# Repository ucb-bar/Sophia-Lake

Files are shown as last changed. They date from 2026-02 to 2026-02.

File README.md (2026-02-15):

# **SOPHIA LAKE**

SL back

# Introduction

Sophia Lake is a general-purpose bring-up carrier board optimized for portability. It is designed around the Bora Lake SODIMM interface to allow for compatibility with a wide array of custom SoCs.

****

Sophia Lake

Art by: [@seuiwu](https://www.instagram.com/seuiwu?utm_source=ig_web_button_share_sheet&igsh=ZDNlZDc0MzIxNw==)

# Block Diagram
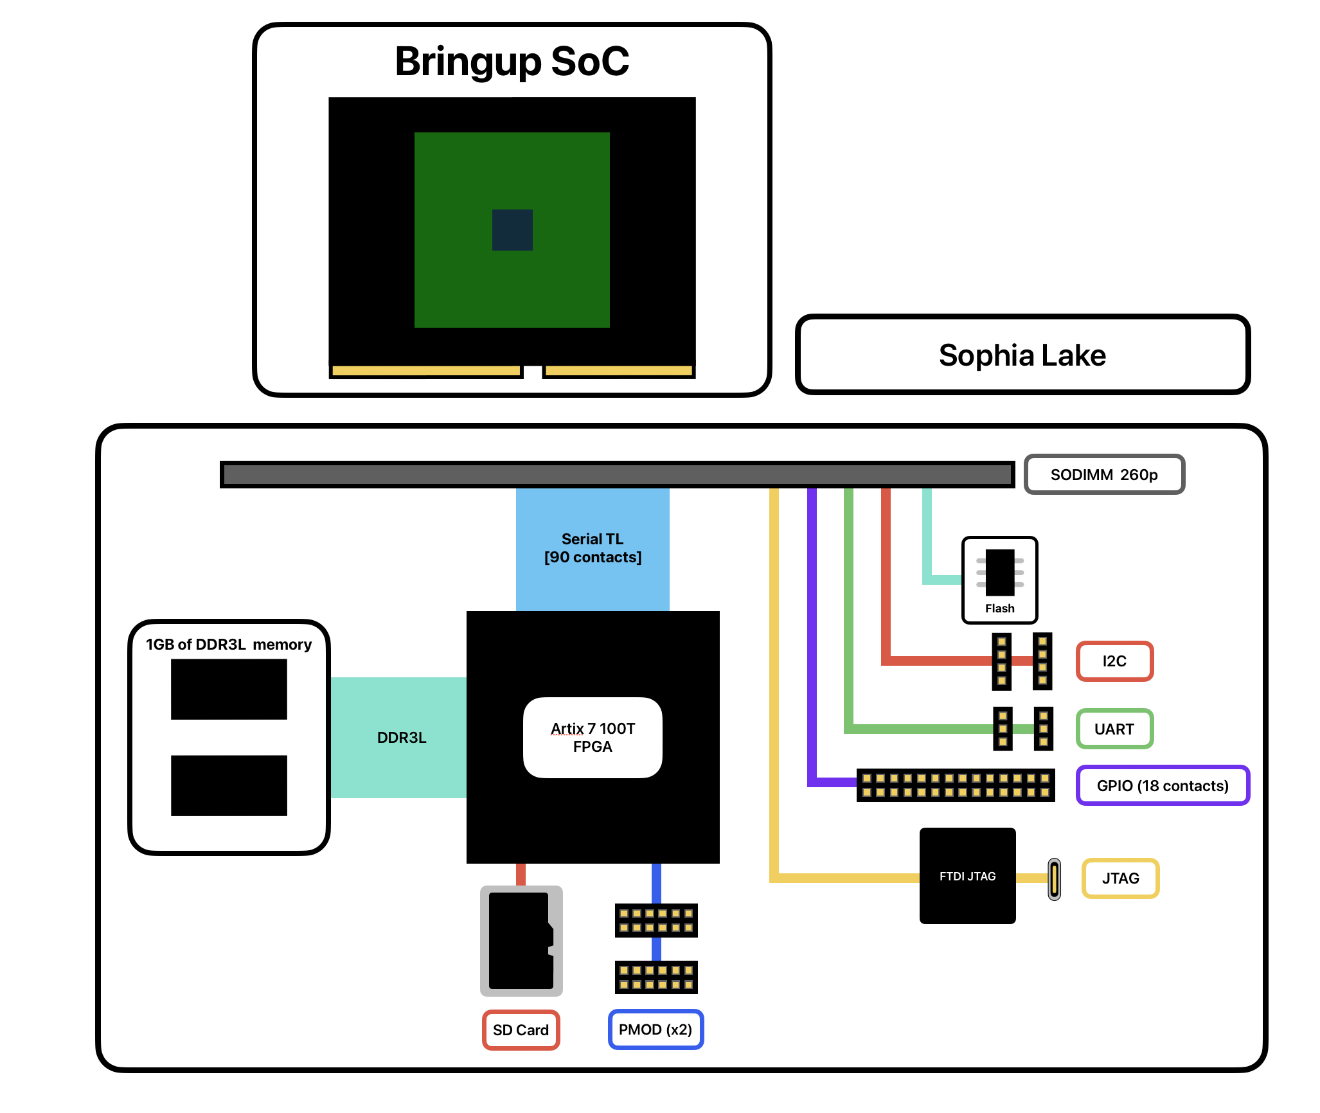
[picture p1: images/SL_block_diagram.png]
Block Diagram


<div style="text-align: center;">

> *"Yufeng's hair style looks like Si-en"*\
>   \- Sophia Shao 

</div>

# Specs
### On-board FPGA
| | Artix A7 100T | Artix A7 200T |
| --- | --- | --- |
| FPGA part | XC7A100T-2FBG484I | XC7A200T-2FBG484I |
| Logic Cells | 101,440 | 215,360 |
| DSP Slices | 240 | 740 | 
| Memory (Kbits) | 4,860 | 13,140 | 

### FPGA Features
- 1GB DDR3L DRAM with 32-bit bus @ 400MHz (800 MT/s)
- 16MB Quad-SPI Flash
- USB-JTAG programming
- MicroSD card slot
- 2x PMOD headers
- 1x Reset button
- 2x Programmable buttons
- 4x LEDs

### SoC Breakout
- 16MB Quad-SPI Flash
- USB-JTAG programming
- Boot select and variable polarity chip reset
- Built-in level shifting to 3.3V
- 4x Programmable buttons
- 4x LEDs
- 2x UART 
- 2x I2C
- 18x GPIO pins

### SoC Power Injection
- Programmable Soc power input
    - VIO input from 1.2V - 3.3V
    - VCORE input from 0.8V - 2.0V
- Optional external power injection
- Shunt resistors for current sensing

# SODIMM Pinout

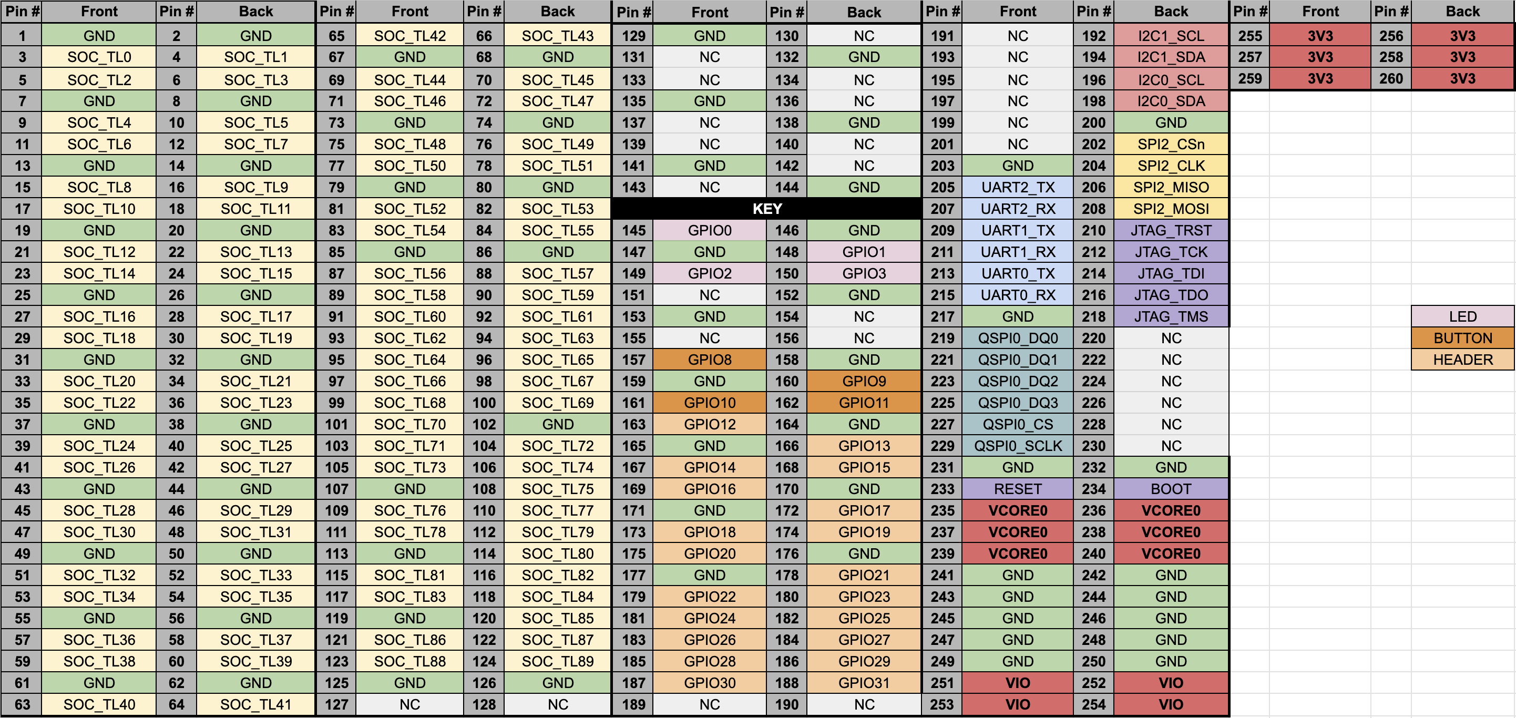
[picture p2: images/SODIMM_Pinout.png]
SODIMM pinout


# Sophia Lake Pinout

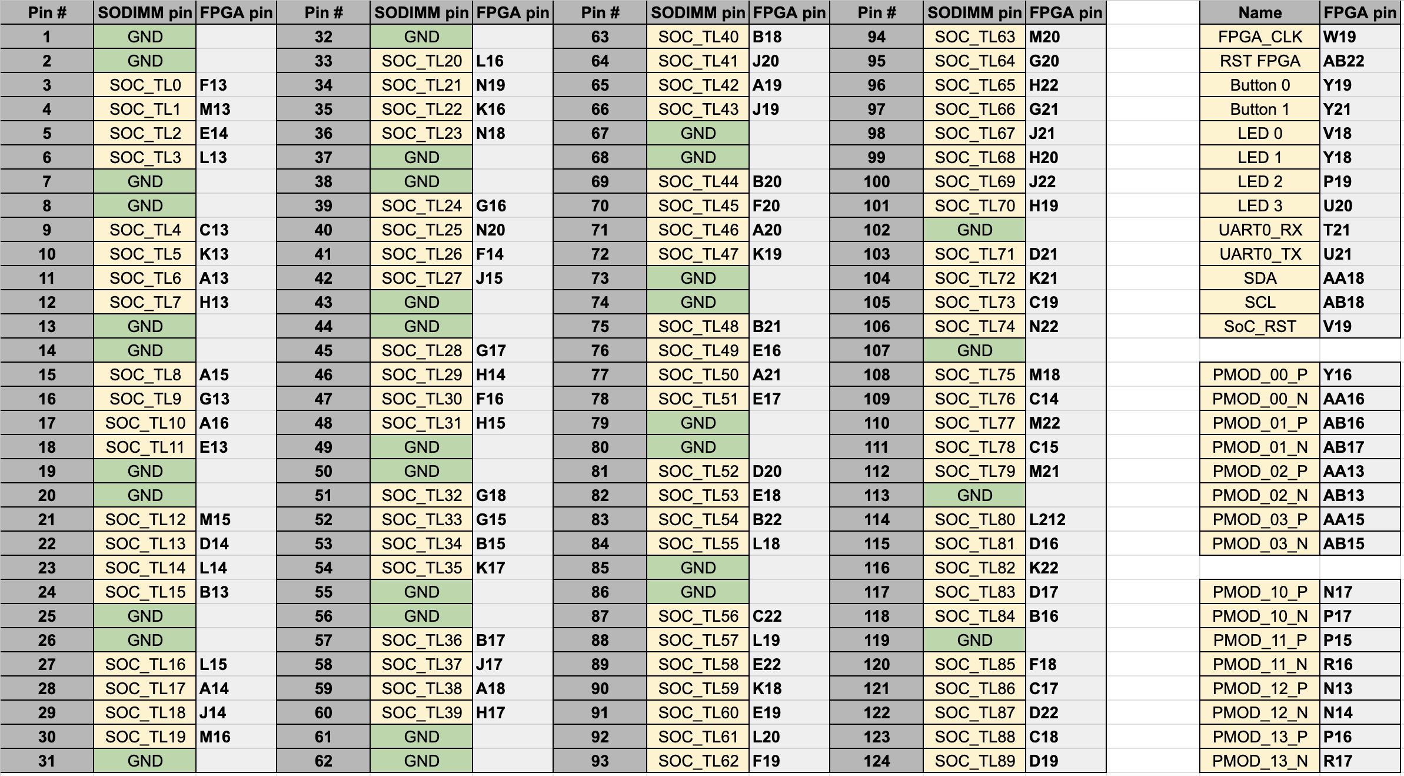
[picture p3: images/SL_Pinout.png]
Sophia Lake pinout


# Board Layout

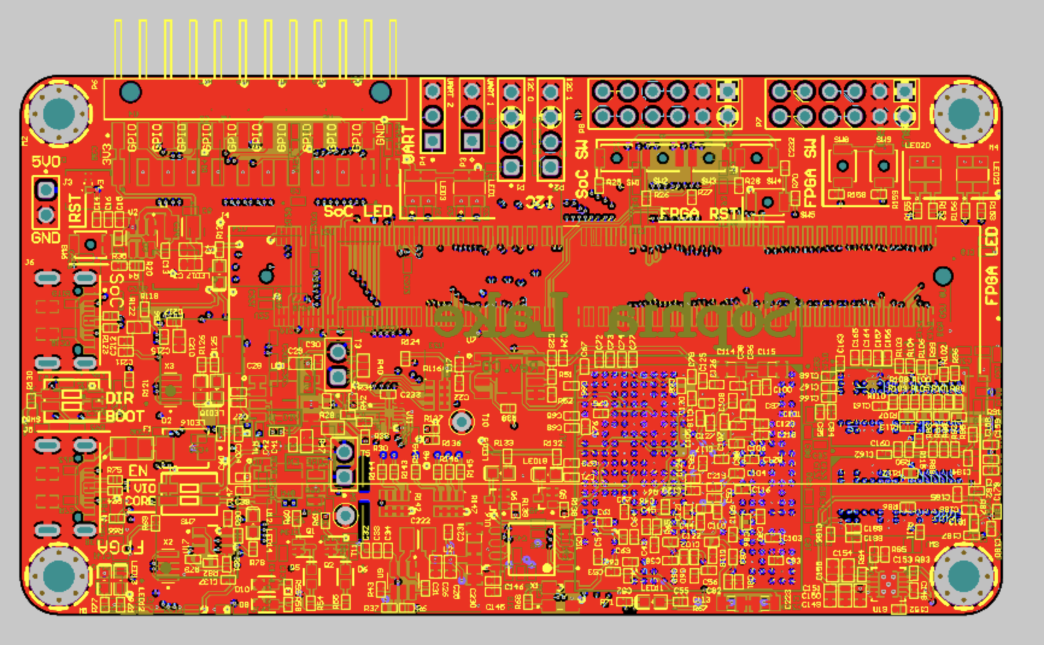
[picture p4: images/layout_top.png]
Layout Top

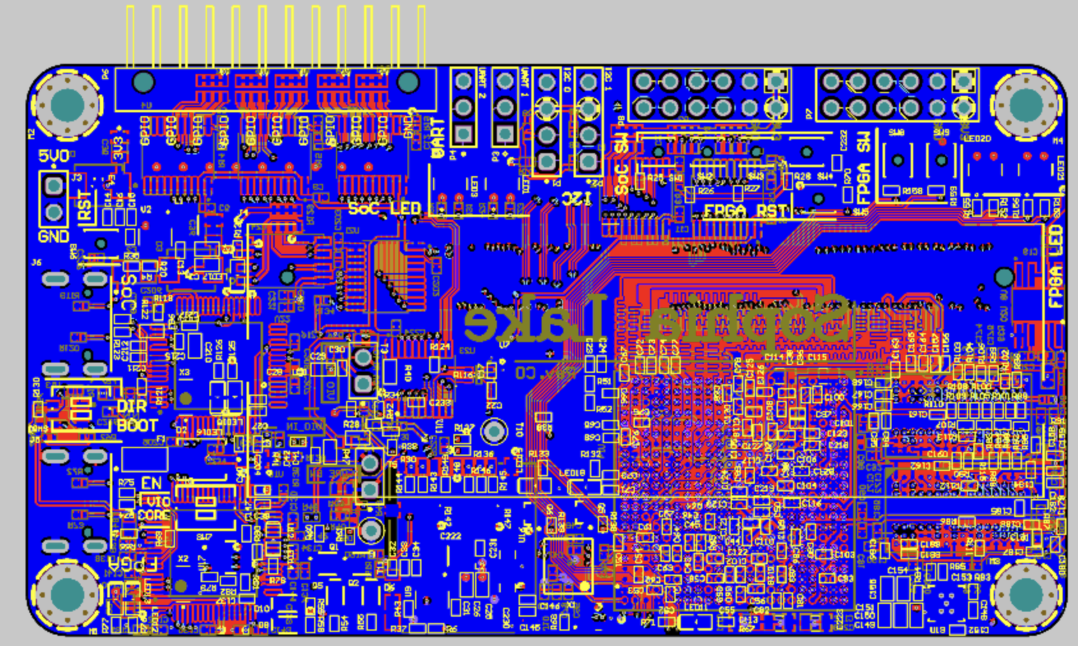
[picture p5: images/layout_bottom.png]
Layout Bottom


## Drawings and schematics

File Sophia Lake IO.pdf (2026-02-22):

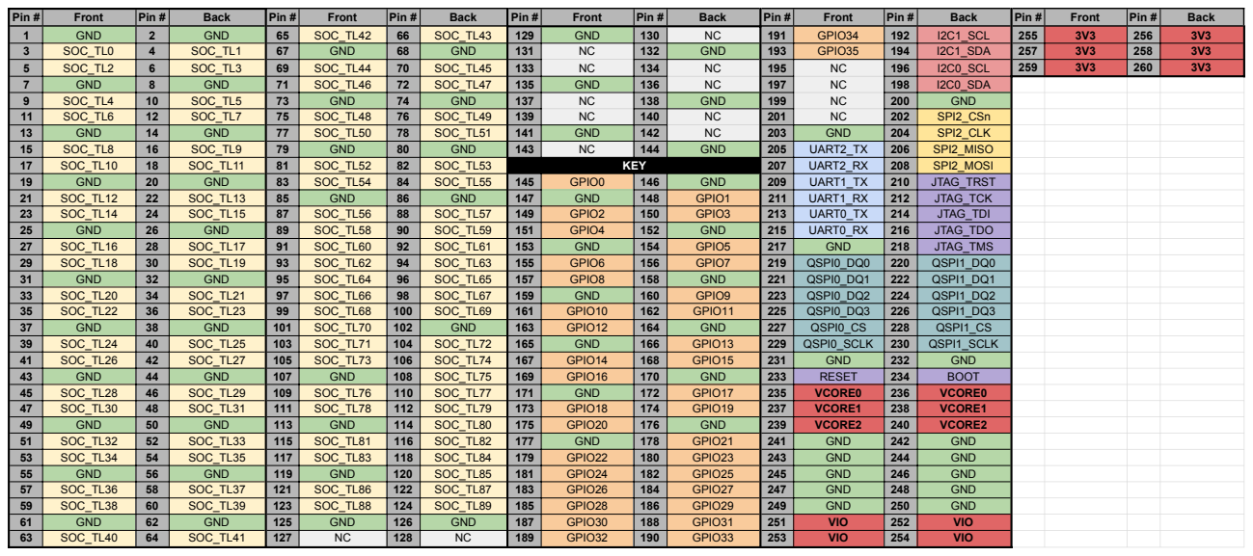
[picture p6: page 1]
Pin #; Front; Back; Back 1; GND; SOC_TL42; SOC_TL43; GPIO34; I2C1_SCL; SOC_TL0; SOC_TL1; GPIO35; I2C1_SDA; SOC_TL2; SOC_TL3; SOC_TL44; SOC_TL45; I2C0_SCL; SOC_TL46; SOC_TL47; I2C0_SDA 9; SOC_TL4; SOC_TL5

11 | SOC_TL6 | 12 | SOC_TL7 | 75 | SOC_TL48 | 76 | SOC_TL49 | 139 | | 140 | NC NC | 201 | | 202 | SPI2_CSn

NC
13 | GND | 14 | GND | 77 | SOC_TL50 | 78 | SOC_TL51 | 141 | GND | 142 | | 203 | GND | 204 | SPI2_CLK
15 | SOC_TL8 | 16 | SOC_TL9 | 79 | GND | 80 | GND | 143 | NC | 144 | GND | 205 | UART2_TX | 206 | SPI2_MISO
17 | SOC_TL10 | 18 | SOC_TL11 | 81 | SOC_TL52 | 82 | SOC_TL53 | KEY | | | | 207 | UART2_RX | 208 | SPI2_MOSI
19 | GND | 20 | GND | 83 | SOC_TL54 | 84 | SOC_TL55 | 145 | GPIO0 GND | 146 | GND | 209 | UART1_TX | 210 | JTAG_TRST
21 | SOC_TL12 | 22 | SOC_TL13 | 85 | GND | 86 | GND | 147 | | 148 | GPIO1 | 211 | UART1_RX | 212 | JTAG_TCK
23 | SOC_TL14 | 24 | SOC_TL15 | 87 | SOC_TL56 | 88 | SOC_TL57 | 149 | GPIO2 | 150 | GPIO3 | 213 | UART0_TX | 214 | JTAG_TDI
25 | GND | 26 | GND | 89 | SOC_TL58 | 90 | SOC_TL59 | 151 | GPIO4 | 152 | GND | 215 | UART0_RX | 216 | JTAG_TDO
27 | SOC_TL16 | 28 | SOC_TL17 | 91 | SOC_TL60 | 92 | SOC_TL61 | 153 | GND | 154 | GPIO5 | 217 | GND | 218 | JTAG_TMS
29 | SOC_TL18 | 30 | SOC_TL19 | 93 | SOC_TL62 | 94 | SOC_TL63 | 155 | GPIO6 | 156 | GPIO7 | 219 | QSPI0_DQ0 | 220 | QSPI1_DQ0
31 | GND | 32 | GND | 95 | SOC_TL64 | 96 | SOC_TL65 | 157 | GPIO8 | 158 | GND | 221 | QSPI0_DQ1 | 222 | QSPI1_DQ1
33 | SOC_TL20 | 34 | SOC_TL21 | 97 | SOC_TL66 | 98 | SOC_TL67 | 159 | GND | 160 | GPIO9 | 223 | QSPI0_DQ2 | 224 | QSPI1_DQ2
35 | SOC_TL22 | 36 | SOC_TL23 | 99 | SOC_TL68 | 100 | SOC_TL69 | 161 | GPIO10 | 162 | GPIO11 | 225 | QSPI0_DQ3 | 226 | QSPI1_DQ3
37 | GND | 38 | GND | 101 | SOC_TL70 | 102 | GND | 163 | GPIO12 | 164 | GND | 227 | QSPI0_CS | 228 | QSPI1_CS
39 | SOC_TL24 | 40 | SOC_TL25 | 103 | SOC_TL71 | 104 | SOC_TL72 | 165 | GND | 166 | GPIO13 | 229 | QSPI0_SCLK | 230 | QSPI1_SCLK
41 | SOC_TL26 | 42 | SOC_TL27 | 105 | SOC_TL73 | 106 | SOC_TL74 | 167 | GPIO14 | 168 | GPIO15 | 231 | GND | 232 | GND
43 | GND | 44 | GND | 107 | GND | 108 | SOC_TL75 | 169 | GPIO16 | 170 | GND | 233 | RESET | 234 | BOOT
45 | SOC_TL28 | 46 | SOC_TL29 | 109 | SOC_TL76 | 110 | SOC_TL77 | 171 | GND | 172 | GPIO17 | 235 | VCORE0 | 236 | VCORE0
47 | SOC_TL30 | 48 | SOC_TL31 | 111 | SOC_TL78 | 112 | SOC_TL79 | 173 | GPIO18 | 174 | GPIO19 | 237 | VCORE1 | 238 | VCORE1
49 | GND | 50 | GND | 113 | GND | 114 | SOC_TL80 | 175 | GPIO20 | 176 | GND | 239 | VCORE2 | 240 | VCORE2
51 | SOC_TL32 | 52 | SOC_TL33 | 115 | SOC_TL81 | 116 | SOC_TL82 | 177 | GND | 178 | GPIO21 | 241 | GND | 242 | GND
53 | SOC_TL34 | 54 | SOC_TL35 | 117 | SOC_TL83 | 118 | SOC_TL84 | 179 | GPIO22 | 180 | GPIO23 | 243 | GND | 244 | GND
55 | GND | 56 | GND | 119 | GND | 120 | SOC_TL85 | 181 | GPIO24 | 182 | GPIO25 | 245 | GND | 246 | GND
57 | SOC_TL36 | 58 | SOC_TL37 | 121 | SOC_TL86 | 122 | SOC_TL87 | 183 | GPIO26 | 184 | GPIO27 | 247 | GND | 248 | GND
59 | SOC_TL38 | 60 | SOC_TL39 | 123 | SOC_TL88 | 124 | SOC_TL89 | 185 | GPIO28 | 186 | GPIO29 | 249 | GND | 250 | GND
61 | GND | 62 | GND | 125 | GND | 126 | GND | 187 | GPIO30 | 188 | GPIO31 | 251 | VIO | 252 | VIO
63 | SOC_TL40 | 64 | SOC_TL41 | 127 | NC | 128 | NC | 189 | GPIO32 | 190 | GPIO33 | 253 | VIO | 254 | VIO

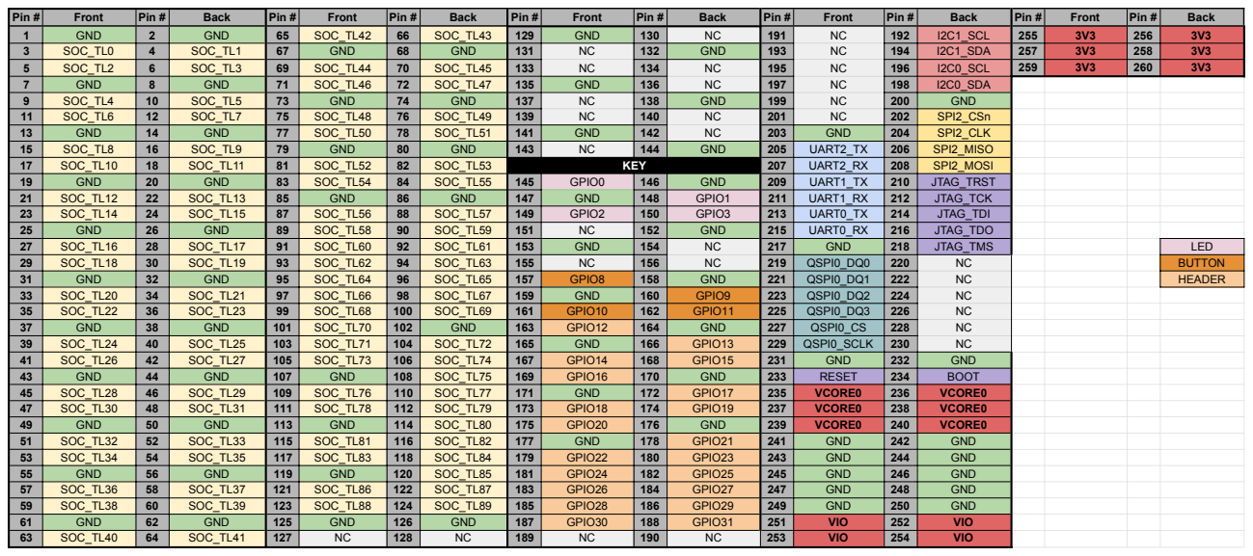
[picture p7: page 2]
SOC_TL16; SOC_TL17; SOC_TL60; SOC_TL61; GND; JTAG_TMS; LED; SOC_TL18; SOC_TL19; SOC_TL62; SOC_TL63; QSPI0_DQ0; BUTTON; SOC_TL64; SOC_TL65; GPIO8; QSPI0_DQ1; HEADER; SOC_TL20; SOC_TL21; SOC_TL66; SOC_TL67; GPIO9; QSPI0_DQ2; SOC_TL22; SOC_TL23; SOC_TL68; SOC_TL69; GPIO10; GPIO11; QSPI0_DQ3; SOC_TL70; GPIO12; QSPI0_CS; SOC_TL24; SOC_TL25; SOC_TL71; SOC_TL72; GPIO13; QSPI0_SCLK
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
